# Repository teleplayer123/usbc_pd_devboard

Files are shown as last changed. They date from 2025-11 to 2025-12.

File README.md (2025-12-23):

### Description
A development board to experiment with USB-C PD via an STM32 and FUSB302. 

The [PD Logger](firmware/pd_logger) firmware logs USB C device attaches and dettaches as well
as the active CC pin. Connect to the board through UART and use a serial terminal to interact with 
the FUSB302 over I2C via the STM32F0. Logs will start showing once a PD capable device is detected.
A debug console menu can be accessed by pressing Enter in the terminal allowing direct writes and
reads to the FUSB302. Press "q" to exit the debug console and return to live logging.

### Dev Board
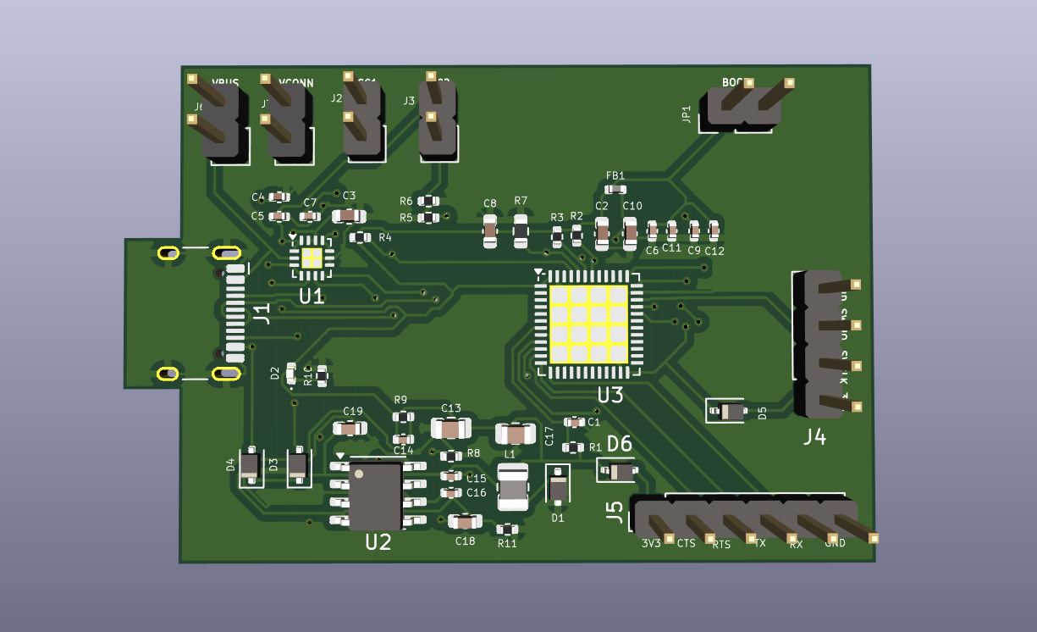
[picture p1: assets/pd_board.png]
DevBoardPreview


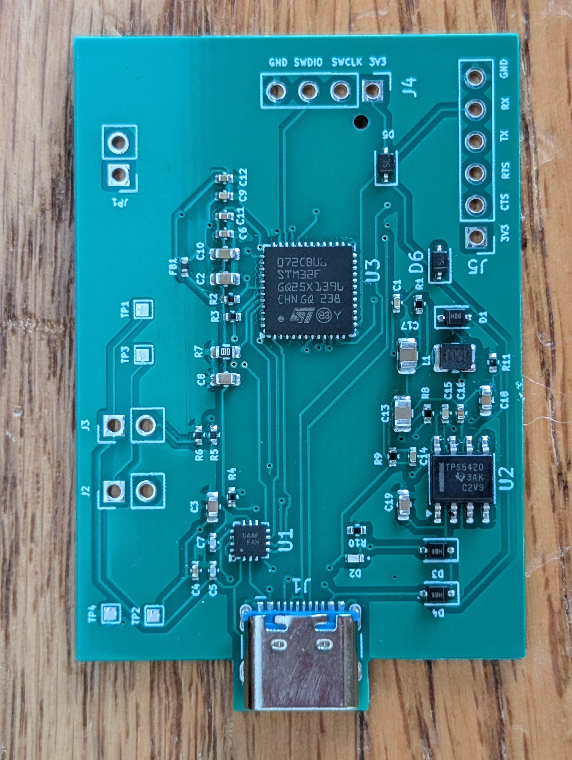
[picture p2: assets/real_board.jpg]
DevBoard


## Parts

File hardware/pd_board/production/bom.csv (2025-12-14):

Designator | Footprint | Quantity | Value | LCSC Part #
C1, C9 | 0402 | 2 | 10nF
C10 | 0603 | 1 | 1uF
C11, C12, C6 | 0402 | 3 | 100nF
C13, C17 | 0805 | 2 | 47uF
C14 | 0402 | 1 | 1800pF
C15 | 0402 | 1 | 0.01uF
C16 | 0402 | 1 | 150pF
C18 | 0603 | 1 | 0.1uF
C19, C2, C8 | 0603 | 3 | 4.7uF
C3 | 0603 | 1 | 10uF
C4 | 0402 | 1 | 0.1uF
C5, C7 | 0402 | 2 | 200pF
D1, D3, D4 | D_SOD-323F | 3 | BAT54J
D2 | 0402 | 1 | PWR_LED
D5, D6 | D_SOD-323 | 2 | 1N5819WS
FB1 | 0402 | 1 | 600R
J1 | USB_C_Receptacle_HCTL_HC-TYPE-C-16P-01A | 1 | USB_C_Receptacle_USB2.0_16P
J2 | PinHeader_1x01_P2.54mm_Vertical | 1 | CC1_TP
J3 | PinHeader_1x01_P2.54mm_Vertical | 1 | CC2_TP
J4 | PinHeader_1x04_P2.54mm_Vertical | 1 | Debug Port
J5 | PinHeader_1x06_P2.54mm_Vertical | 1 | UART_Port
J6 | PinHeader_1x02_P2.54mm_Vertical | 1 | VBUS_JP
J7 | PinHeader_1x02_P2.54mm_Vertical | 1 | VCONN_JP
J8 | PinHeader_1x02_P2.54mm_Vertical | 1 | VIN_ENA_JP
JP1 | PinHeader_1x02_P2.54mm_Vertical | 1 | Boot_Jumper
L1 | 1008 | 1 | 18uH
R1, R9 | 0402 | 2 | 10k
R10 | 0402 | 1 | 1k
R11 | 0402 | 1 | 5.9k
R2, R3, R4 | 0402 | 3 | 4.7k
R7 | 0603 | 1 | 100k
R8 | 0402 | 1 | 549R
U1 | WQFN-14-1EP_2.5x2.5mm_P0.5mm_EP1.45x1.45mm | 1 | FUSB302BMPX
U2 | SOIC-8_3.9x4.9mm_P1.27mm | 1 | TPS5420D
U3 | QFN-48-1EP_7x7mm_P0.5mm_EP5.6x5.6mm | 1 | STM32F072CBUx

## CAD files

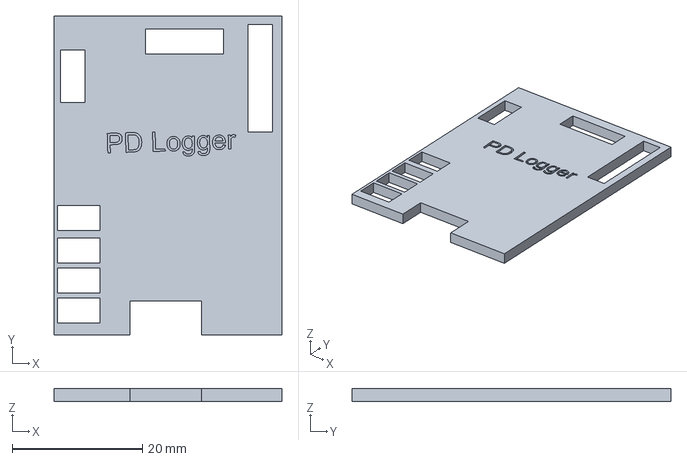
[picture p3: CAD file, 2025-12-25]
case/pd_board-Body001.3mf
35.0 x 49.0 x 2.00 mm

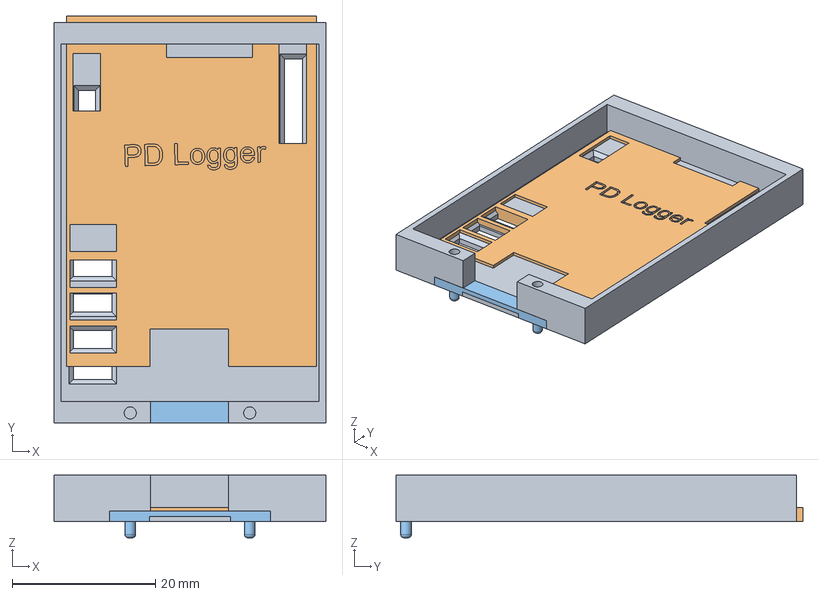
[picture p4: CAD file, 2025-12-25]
case/pd_board.FCStd
38.0 x 56.9 x 8.75 mm

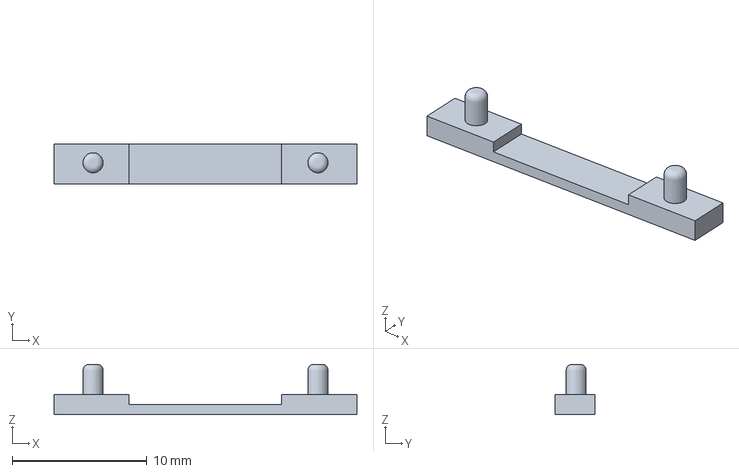
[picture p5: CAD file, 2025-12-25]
case/pd_board-Body002.3mf
22.5 x 3.00 x 3.75 mm

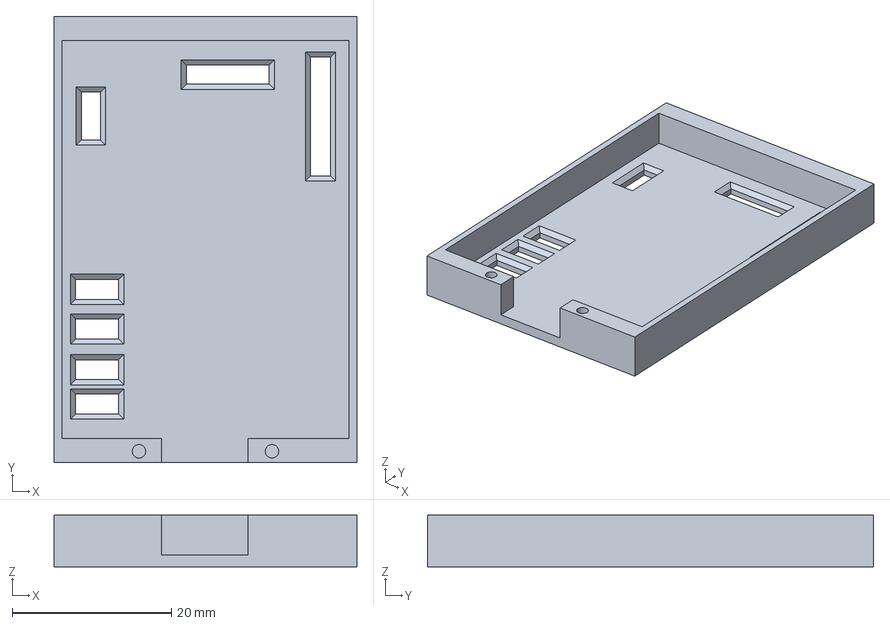
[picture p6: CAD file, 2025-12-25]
case/pd_board-Body.3mf
38.0 x 56.0 x 6.50 mm

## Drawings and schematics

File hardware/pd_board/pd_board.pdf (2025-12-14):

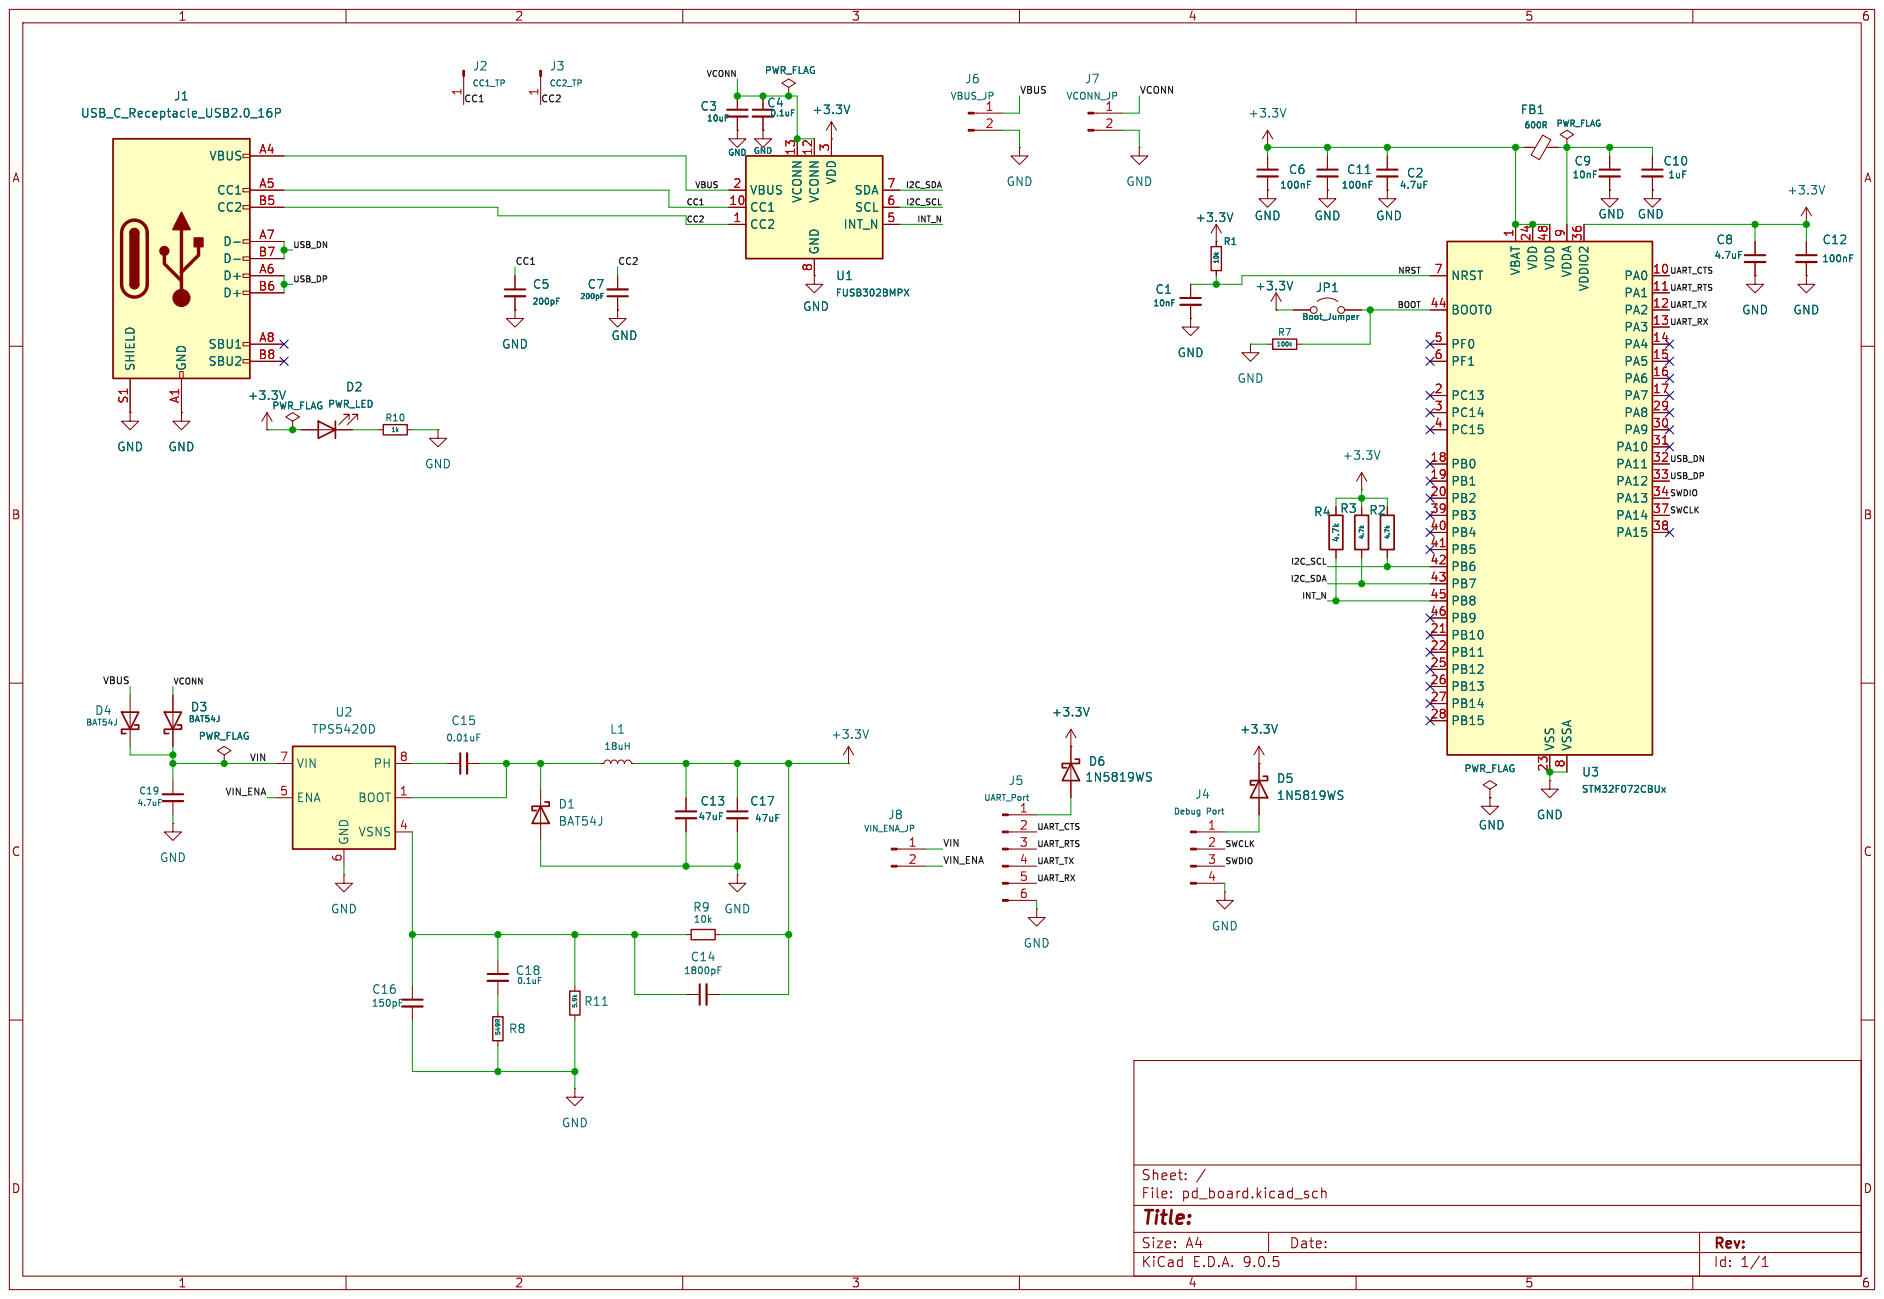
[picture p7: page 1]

1 VDD 24 VDD 48 VSS 23 VDDA

Id: 1/1 Title: File: pd_board.kicad_sch Sheet: /

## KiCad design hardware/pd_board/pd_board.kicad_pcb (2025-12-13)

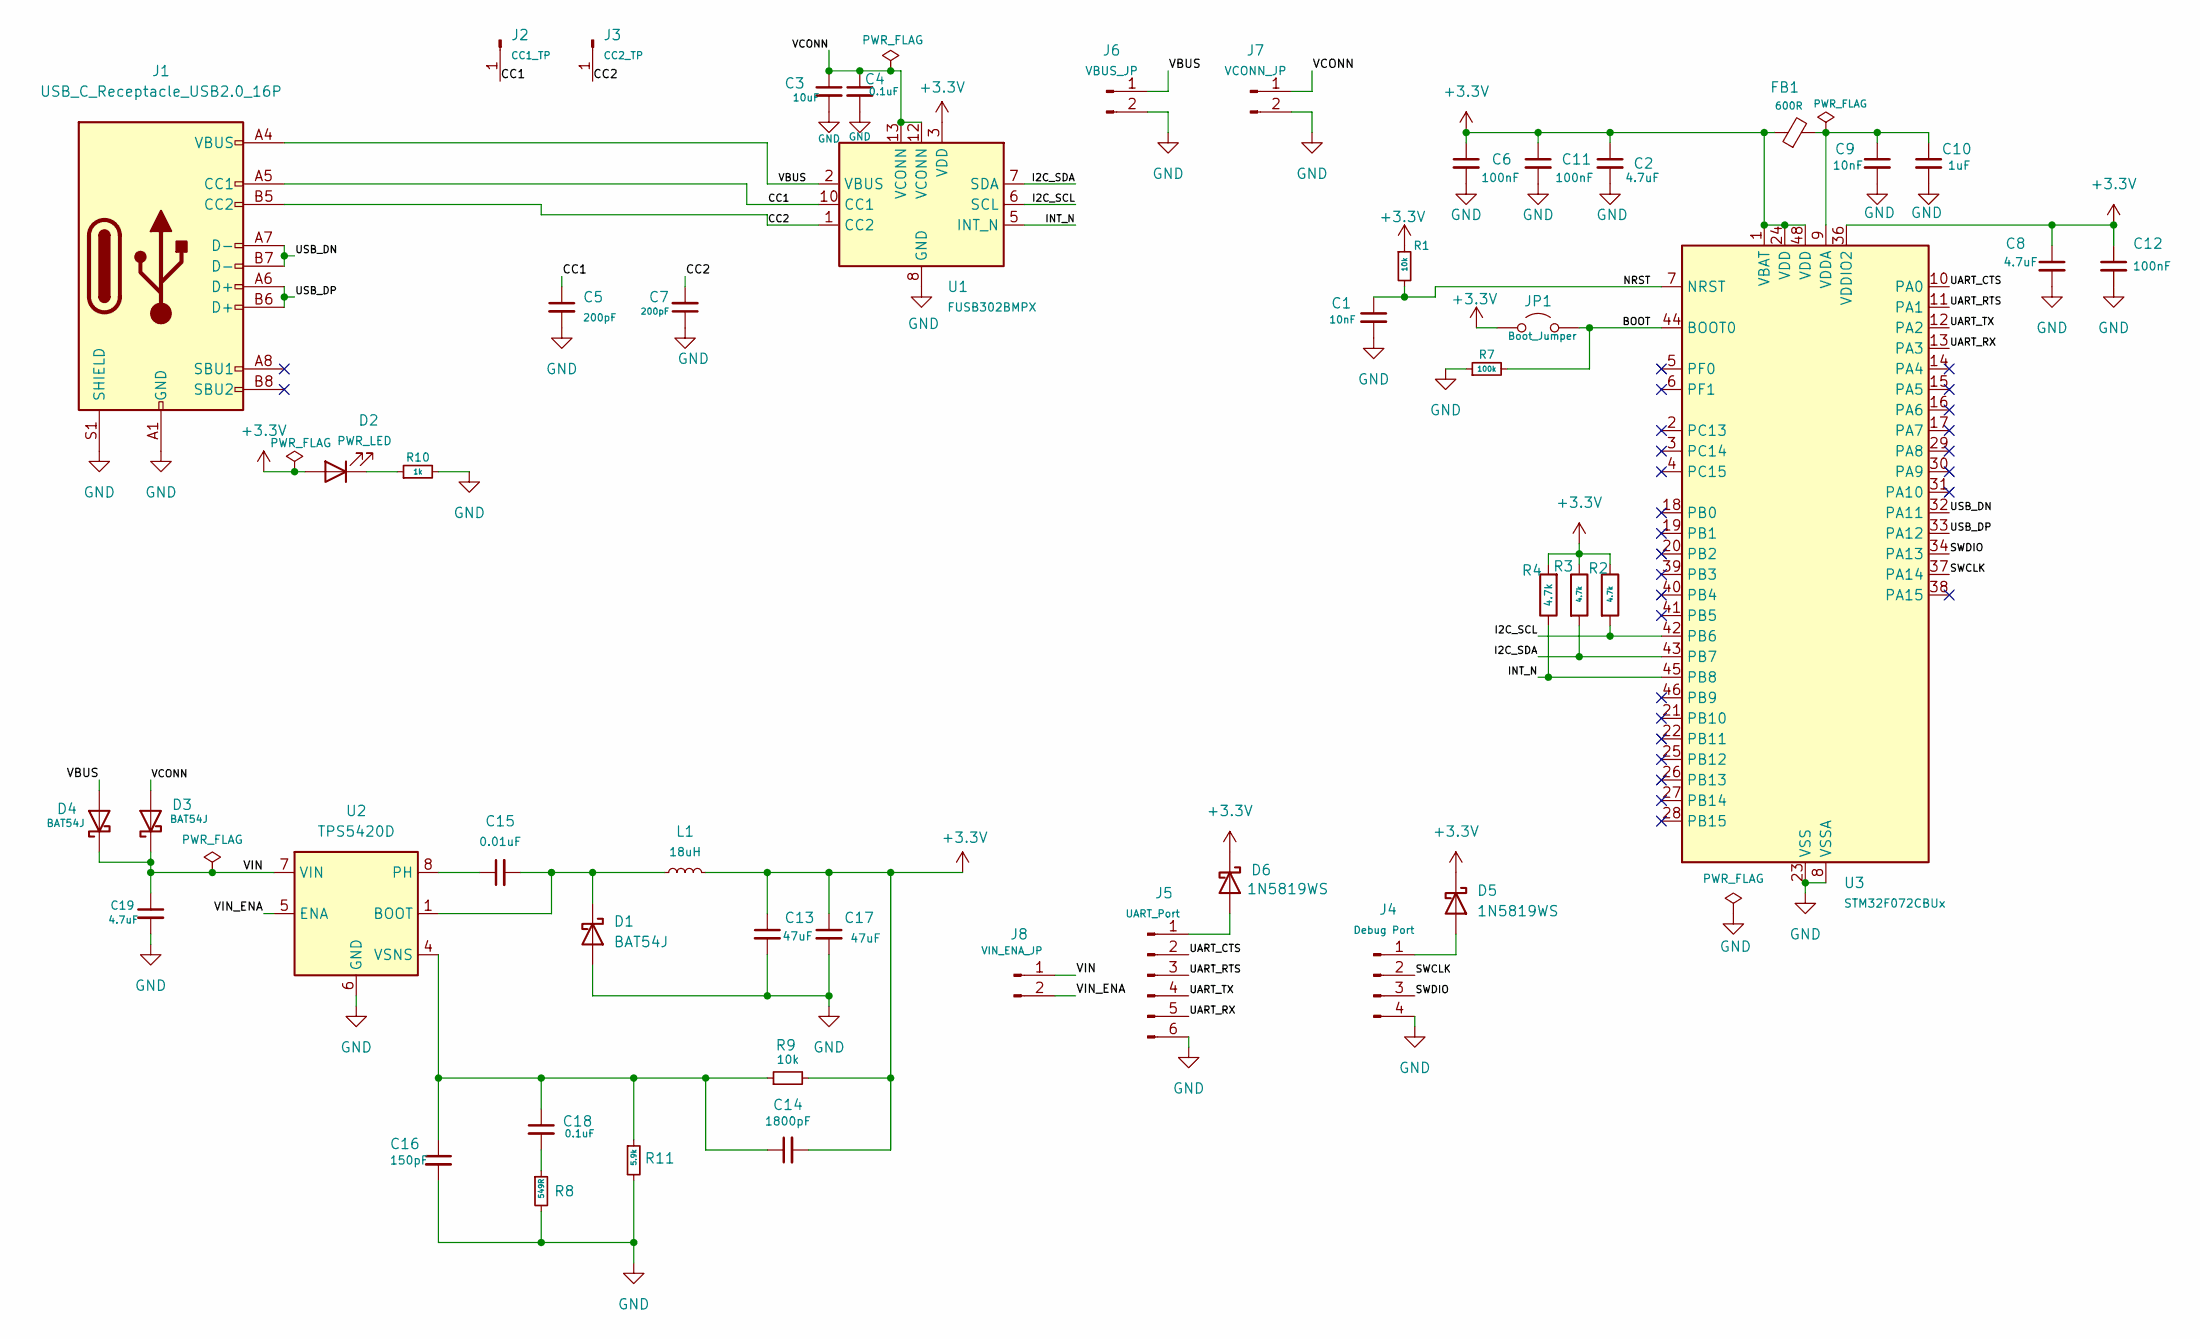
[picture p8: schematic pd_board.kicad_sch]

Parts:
C1, C9: 10nF; C_0402_1005Metric
C2, C8, C19: 4.7uF; C_0603_1608Metric
C3: 10uF; C_0603_1608Metric
C4: 0.1uF; C_0402_1005Metric
C5, C7: 200pF; C_0402_1005Metric
C6, C11, C12: 100nF; C_0402_1005Metric
C10: 1uF; C_0603_1608Metric
C13, C17: 47uF; C_0805_2012Metric
C14: 1800pF; C_0402_1005Metric
C15: 0.01uF; C_0402_1005Metric
C16: 150pF; C_0402_1005Metric
C18: 0.1uF; C_0603_1608Metric
D1, D3, D4: BAT54J; D_SOD-323F
D2: PWR_LED; LED_0402_1005Metric
D5, D6: 1N5819WS; D_SOD-323
FB1: 600R; L_0402_1005Metric
J1: USB_C_Receptacle_USB2.0_16P; USB_C_Receptacle_HCTL_HC-TYPE-C-16P-01A
J2: CC1_TP; PinHeader_1x01_P2.54mm_Vertical
J3: CC2_TP; PinHeader_1x01_P2.54mm_Vertical
J4: Debug Port; PinHeader_1x04_P2.54mm_Vertical
J5: UART_Port; PinHeader_1x06_P2.54mm_Vertical
J6: VBUS_JP; PinHeader_1x02_P2.54mm_Vertical
J7: VCONN_JP; PinHeader_1x02_P2.54mm_Vertical
J8: VIN_ENA_JP; PinHeader_1x02_P2.54mm_Vertical
JP1: Boot_Jumper; PinHeader_1x02_P2.54mm_Vertical
L1: 18uH; L_1008_2520Metric
R1, R9: 10k; R_0402_1005Metric
R2, R3, R4: 4.7k; R_0402_1005Metric
R7: 100k; R_0603_1608Metric
R8: 549R; R_0402_1005Metric
R10: 1k; R_0402_1005Metric
R11: 5.9k; R_0402_1005Metric
U1: FUSB302BMPX; WQFN-14-1EP_2.5x2.5mm_P0.5mm_EP1.45x1.45mm
U2: TPS5420D; SOIC-8_3.9x4.9mm_P1.27mm
U3: STM32F072CBUx; QFN-48-1EP_7x7mm_P0.5mm_EP5.6x5.6mm

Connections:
+3.3V: C2.1, C6.1, C8.1, C11.1, C12.1, C13.1, C14.2, C17.1, D2.2 (A), D5.1 (K), D6.1 (K), FB1.1, JP1.1 (A), L1.2, R1.1, R2.1, R3.1, R4.2, R9.2, U1.3 (VDD), U1.4 (VDD), U3.1 (VBAT), U3.24 (VDD), U3.36 (VDDIO2), U3.48 (VDD)
/BOOT: JP1.2 (B), R7.2, U3.44 (BOOT0)
/CC1: C5.1, J1.A5 (CC1), J2.1, U1.10 (CC1), U1.11 (CC1)
/CC2: C7.2, J1.B5 (CC2), J3.1, U1.1 (CC2), U1.14 (CC2)
/I2C_SCL: R2.2, U1.6 (SCL), U3.42 (PB6)
/I2C_SDA: R3.2, U1.7 (SDA), U3.43 (PB7)
/INT_N: R4.1, U1.5 (INT_N), U3.45 (PB8)
/NRST: C1.1, R1.2, U3.7 (NRST)
/SWCLK: J4.2, U3.37 (PA14)
/SWDIO: J4.3, U3.34 (PA13)
/UART_CTS: J5.2, U3.10 (PA0)
/UART_RTS: J5.3, U3.11 (PA1)
/UART_RX: J5.5, U3.13 (PA3)
/UART_TX: J5.4, U3.12 (PA2)
/USB_DN: J1.A7 (D-), J1.B7 (D-), U3.32 (PA11)
/USB_DP: J1.A6 (D+), J1.B6 (D+), U3.33 (PA12)
/VBUS: D4.2 (A), J1.A4 (VBUS), J1.A9 (VBUS), J1.B4 (VBUS), J1.B9 (VBUS), J6.1, U1.2 (VBUS)
/VCONN: C3.1, C4.1, D3.2 (A), J7.1, U1.12 (VCONN), U1.13 (VCONN)
/VIN: C19.1, D3.1 (K), D4.1 (K), J8.1, U2.7 (VIN)
/VIN_ENA: J8.2, U2.5 (ENA)
GND: C1.2, C2.2, C3.2, C4.2, C5.2, C6.2, C7.1, C8.2, C9.2, C10.2, C11.2, C12.2, C13.2, C16.2, C17.2, C19.2, D1.2 (A), J1.A1 (GND), J1.A12 (GND), J1.B1 (GND), J1.B12 (GND), J1.S1 (SHIELD), J4.4, J5.6, J6.2, J7.2, R7.1, R8.2, R10.2, R11.2, U1.8 (GND), U1.9 (GND), U1.15 (GND), U2.6 (GND), U3.8 (VSSA), U3.23 (VSS), U3.35 (VSS), U3.47 (VSS), U3.49 (VSS)
unnamed: C18.2, R8.1
unnamed: C15.2, D1.1 (K), L1.1, U2.1 (BOOT)
unnamed: D2.1 (K), R10.1
unnamed: D5.2 (A), J4.1
unnamed: D6.2 (A), J5.1
unnamed: C15.1, U2.8 (PH)
unnamed: C14.1, C16.1, C18.1, R9.1, R11.1, U2.4 (VSNS)
unnamed: C9.1, C10.1, FB1.2, U3.9 (VDDA)

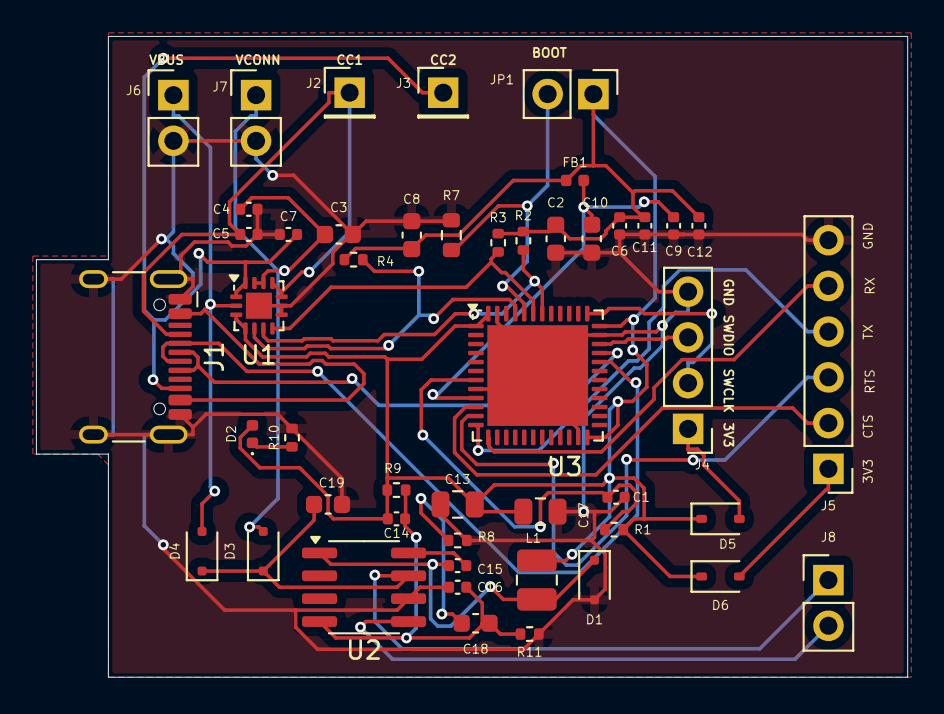
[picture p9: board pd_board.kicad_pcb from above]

Board: 2 copper layers, 48.4 x 35.6 mm, 48 parts (0 on the bottom side), 29 nets.

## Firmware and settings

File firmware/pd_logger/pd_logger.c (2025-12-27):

#include <libopencm3/stm32/rcc.h>
#include <libopencm3/stm32/gpio.h>
#include <libopencm3/stm32/usart.h>
#include <libopencm3/stm32/i2c.h>
#include <libopencm3/stm32/exti.h>
#include <libopencm3/cm3/nvic.h>
#include <libopencm3/cm3/cortex.h>
#include <libopencm3/cm3/systick.h>
#include <stdio.h>
#include <stdarg.h>
#include <string.h>
#include <stdlib.h>
#include <stdint.h>
#include <stdbool.h>
#include "fusb302.h"

/* ------------------------------------------------------------
 * Globals
 * ------------------------------------------------------------ */

volatile uint32_t system_millis;

static struct fusb302_chip_state {
    // CC1 = 0, CC2 = 1
	int cc_polarity;
	int vconn_enabled;
	// pulling up (DFP) = 1, pulling down (UFP) = 0
	int pulling_up;
	int rx_enable;
	uint8_t mdac_vnc;
	uint8_t mdac_rd;
    // device attached = 1, no device attached = 0
    int attached;
} state;

/* ------------------------------------------------------------
 * MCU Setup Functions
 * ------------------------------------------------------------ */

void sys_tick_handler(void)
{
    system_millis++;
}

static void clock_setup(void)
{
    rcc_clock_setup_in_hsi_out_48mhz();
    rcc_periph_clock_enable(RCC_GPIOA);
    rcc_periph_clock_enable(RCC_GPIOB);
    rcc_periph_clock_enable(RCC_USART2);
    rcc_periph_clock_enable(RCC_I2C1);
    // We need to enable the clock for SYSCFG to configure EXTI.
    rcc_periph_clock_enable(RCC_SYSCFG_COMP);
}

static void usart_setup(void)
{
    gpio_mode_setup(GPIOA, GPIO_MODE_AF, GPIO_PUPD_NONE, GPIO2 | GPIO3);
    gpio_set_af(GPIOA, GPIO_AF1, GPIO2 | GPIO3);
    // usart_disable(USART2);
    usart_set_baudrate(USART2, 115200);
    usart_set_databits(USART2, 8);
    usart_set_stopbits(USART2, USART_STOPBITS_1);
    usart_set_parity(USART2, USART_PARITY_NONE);
    usart_set_mode(USART2, USART_MODE_TX_RX);
    usart_set_flow_control(USART2, USART_FLOWCONTROL_NONE);
    usart_enable(USART2);
}

static void i2c_setup(void)
{
    gpio_mode_setup(GPIOB, GPIO_MODE_AF, GPIO_PUPD_NONE, GPIO6 | GPIO7);
    gpio_set_output_options(GPIOB, GPIO_OTYPE_OD, GPIO_OSPEED_25MHZ, GPIO6 | GPIO7);
    gpio_set_af(GPIOB, GPIO_AF1, GPIO6 | GPIO7);
    // gpio_mode_setup(GPIOB, GPIO_MODE_INPUT, GPIO_PUPD_NONE, GPIO8);
    gpio_mode_setup(GPIOB, GPIO_MODE_INPUT, GPIO_PUPD_PULLUP, GPIO8);

    // Hardware reset via RCC 
    rcc_peripheral_reset(&RCC_APB1RSTR, RCC_APB1RSTR_I2C1RST);
    rcc_peripheral_clear_reset(&RCC_APB1RSTR, RCC_APB1RSTR_I2C1RST);

    i2c_peripheral_disable(I2C1);
    i2c_set_speed(I2C1, i2c_speed_fm_400k, rcc_apb1_frequency / 1e6);
    i2c_peripheral_enable(I2C1);
}

static void systick_setup(void)
{
    systick_set_reload(rcc_ahb_frequency / 1000 - 1);
    systick_set_clocksource(STK_CSR_CLKSOURCE_AHB);
    systick_counter_enable();
    systick_interrupt_enable();
}

static void exti_setup(void)
{
    // Map PB8 to EXTI8
    exti_select_source(EXTI8, GPIOB);

    // Set EXTI8 to trigger on a falling edge (INT_N is active-low)
    exti_set_trigger(EXTI8, EXTI_TRIGGER_FALLING);

    // Enable EXTI8 interrupt line
    exti_enable_request(EXTI8);

    /* Source Identification: Inside the EXTI4_15_IRQHandler function, you will 
    need to check the specific pending register flag (PR register, bit 8) for EXTI 
    line 8 to determine if it was the source of the interrupt, as lines 4 through 15 
    all share this single handler */
    nvic_enable_irq(NVIC_EXTI4_15_IRQ); 
}

/* ------------------------------------------------------------
 * USART logging functions
 * ------------------------------------------------------------ */

/* simple blocking getchar/putchar */
int _write(int fd, char *ptr, int len)
{
    (void)fd;
    for (int i=0; i<len; i++) usart_send_blocking(USART2, ptr[i]);
    return len;
}

static void usart_send_char(char c)
{
    usart_send_blocking(USART2, c);
}

static char usart_getc(void)
{ 
    return usart_recv_blocking(USART2); 
}

static void usart_printf(const char *format, ...)
{
    char buf[2048];
    va_list args;
    va_start(args, format);
    vsnprintf(buf, sizeof(buf), format, args);
    va_end(args);

    for (const char *p = buf; *p; p++) {
        usart_send_char(*p);
        // Handle newline conversion for terminal compatibility
        if (*p == '\n') {
            usart_send_char('\r');
        }
    }
}

static void print_byte_as_bits(uint8_t byte, uint8_t reg)
{
    usart_printf("Reg %02X: ", reg);
    for (int i = 7; i >= 0; i--) { // Loop from most significant bit (7) to least significant (0)
        // Use a bitwise AND with a mask to check if the current bit is set
        // The mask is 1 shifted left by 'i' positions
        if ((byte >> i) & 1) { 
            usart_printf("1");
        } else {
            usart_printf("0");
        }
    }
    usart_printf("\r\n");
}

static void dump_bits(uint8_t reg, const struct bit_name *tbl)
{
    for (int i = 0; i <= 7; i++) {
        if (tbl[i].name == NULL)
            continue;  // skip unused bits             

        usart_printf("%s = %d\n", tbl[i].name, !!(reg & tbl[i].mask));
    }
}

static void hexdump(const uint8_t *data, size_t len)
{
    for (size_t i = 0; i < len; i += 16) {
        usart_printf("%04X: ", (unsigned int)i);
        
        // Print hex bytes
        for (size_t j = 0; j < 16 && i + j < len; j++) {
            usart_printf("%02X ", data[i + j]);
        }
        
        // Padding for alignment
        for (size_t j = len - i; j < 16; j++) {
            usart_printf("   ");
        }
        
        // Print ASCII representation
        usart_printf(" | ");
        for (size_t j = 0; j < 16 && i + j < len; j++) {
            uint8_t c = data[i + j];
            usart_printf("%c", (c >= 32 && c < 127) ? c : '.');
        }
        usart_printf("\r\n");
    }
}

static inline bool usart_rx_ready(void)
{
    return usart_get_flag(USART2, USART_FLAG_RXNE);
}

/* ------------------------------------------------------------
 * I2C read/write functions
 * ------------------------------------------------------------ */

static void fusb_write(uint8_t reg, uint8_t val)
{
    uint8_t tx_buf[2] = {reg, val};
    i2c_transfer7(I2C1, FUSB302_ADDR, tx_buf, 2, NULL, 0);
}

static inline uint8_t fusb_read(uint8_t reg)
{
    uint8_t v;
    i2c_transfer7(I2C1, FUSB302_ADDR, &reg, 1, &v, 1);
    return v;
}

static inline void fusb_read_fifo(uint8_t *buf, int len)
{
    uint8_t r = FUSB302_REG_FIFOS;
    i2c_transfer7(I2C1, FUSB302_ADDR, &r, 1, buf, len);
}

/* ------------------------------------------------------------
 * FUSB302 functions
 * ------------------------------------------------------------ */

static inline bool fusb_rx_empty(void) 
{
    return fusb_read(FUSB302_REG_STATUS1) & FUSB302_STATUS1_RX_EMPTY;
}

static void fusb_delay_ms(uint32_t ms)
{
    // This assumes SysTick is running at 1ms intervals.
    for (uint32_t i = 0; i < ms; i++) {
        // Wait for the SysTick flag to be set (1ms elapsed)
        while ((STK_CSR & STK_CSR_COUNTFLAG) == 0);
    }
}

static void fusb_delay_us(uint32_t us) {
    // At 48MHz, approximately 48 clock cycles per microsecond
    // Each NOP takes 1 cycle, loop overhead is minimal
    for (uint32_t i = 0; i < us * 6; i++) {
        __asm__("nop");
    }
}

static void fusb_reset(void)
{
    fusb_write(FUSB302_REG_RESET, FUSB302_RESET_SW);
    fusb_delay_ms(2);
}

static void fusb_pd_reset(void)
{
    fusb_write(FUSB302_REG_RESET, FUSB302_RESET_PD);
    fusb_delay_ms(2);
}

static void fusb_power_all(void)
{
    fusb_write(FUSB302_REG_POWER, FUSB302_POWER_ALL_ON);
    fusb_delay_ms(1);
}

// Print current state struct values for debugging
static void fusb_current_state(void)
{
    usart_printf("---- Current FUSB302 State ----\r\n");
    usart_printf("CC Polarity: %d\r\n", state.cc_polarity);
    usart_printf("VCONN Enabled: %d\r\n", state.vconn_enabled);
    if (state.pulling_up) {
        usart_printf("Pulling Up (DFP): %d\r\n", state.pulling_up);
    } else {
        usart_printf("Pulling Down (UFP): %d\r\n", state.pulling_up);
    }
    usart_printf("RX Enable: %d\r\n", state.rx_enable);
    usart_printf("MDAC VNC: 0x%02X\r\n", state.mdac_vnc);
    usart_printf("MDAC RD: 0x%02X\r\n", state.mdac_rd);
    if (state.attached) {
        usart_printf("Device Attached: True\r\n");
    } else {
        usart_printf("Device Attached: False\r\n");
    }
    usart_printf("---- End State ----\r\n");
}

/*
// unused functions being kept as reference for now...
static void fusb_setup_sniffer(void)
{    
    uint8_t reg;

    usart_printf("Initializing FUSB302 for PD Sniffing...\n");

    state.mdac_vnc = FUSB302_MEAS_MDAC_MV(PD_SRC_DEF_MV);
    state.mdac_rd = FUSB302_MEAS_MDAC_MV(PD_SRC_DEF_RD_MV);
    
    // Reset the FUSB302
    fusb_reset();

    // Power on
    fusb_power_all();

    // Configure Switches0: Enable measurement (passive detection) on CC1 and CC2
    reg = fusb_read(FUSB302_REG_SWITCHES0);
    reg |= (FUSB302_SW0_MEAS_CC1 | FUSB302_SW0_MEAS_CC2 | FUSB302_SW0_PDWN1 | FUSB302_SW0_PDWN2);
    fusb_write(FUSB302_REG_SWITCHES0, reg);

    // Configure Control1: Enable reception of all SOP packets
    fusb_write(FUSB302_REG_CONTROL1, FUSB302_CTL1_ENSOP1 | FUSB302_CTL1_ENSOP2 | FUSB302_CTL1_ENSOP1DB | FUSB302_CTL1_ENSOP2DB);

    // Enable Auto-CRC, Set sink role
    fusb_write(FUSB302_REG_SWITCHES1, FUSB302_SW1_AUTO_GCRC | FUSB302_SW1_SPECREV1 | FUSB302_SW1_SPECREV0);

    // Toggle to detect CC and establish UFP (Sink)
    fusb_write(FUSB302_REG_CONTROL2, FUSB302_CTL2_MODE_UFP | FUSB302_CTL2_WAKE_EN | FUSB302_CTL2_TOGGLE);

    // Unmask all interrupts
    fusb_write(FUSB302_REG_MASK, 0x00);
    fusb_write(FUSB302_REG_MASKA, 0x00);
    fusb_write(FUSB302_REG_MASKB, 0x00);

    // Reading interrupts clears them
    fusb_read(FUSB302_REG_INTERRUPT);
    fusb_read(FUSB302_REG_INTERRUPTA);
    fusb_read(FUSB302_REG_INTERRUPTB);
    fusb_delay_ms(2);

    // Set VCONN and polarity defaults
    state.vconn_enabled = 0;
    state.cc_polarity = 0;
    // Pull-down enabled
    state.pulling_up = 0;
    // RX enabled
    state.rx_enable = 1;

    usart_printf("FUSB302 configured for PD Sniffing.\n");
}

static void fusb_init_sink(void)
{
    // CONTROL1 Enable reception of all SOP packets
    fusb_write(FUSB302_REG_CONTROL1, FUSB302_CTL1_ENSOP1 | FUSB302_CTL1_ENSOP2 | FUSB302_CTL1_ENSOP1DB | FUSB302_CTL1_ENSOP2DB);

    // SWITCHES1 Enable Auto-CRC, Set sink role
    fusb_write(FUSB302_REG_SWITCHES1, FUSB302_SW1_AUTO_GCRC | FUSB302_SW1_SPECREV1 | FUSB302_SW1_SPECREV0);
    // CONTROL2 Toggle to detect CC and establish UFP (Sink)
    fusb_write(FUSB302_REG_CONTROL2, FUSB302_CTL2_MODE_UFP | FUSB302_CTL2_WAKE_EN | FUSB302_CTL2_TOGGLE);

    // SWITCHES0 Enable measurement (passive detection) on CC1 and CC2
    uint8_t reg = fusb_read(FUSB302_REG_SWITCHES0);
    reg |= (FUSB302_SW0_MEAS_CC1 | FUSB302_SW0_MEAS_CC2 | FUSB302_SW0_PDWN1 | FUSB302_SW0_PDWN2);
    fusb_write(FUSB302_REG_SWITCHES0, reg);

    usart_printf("FUSB302 initialized in Sink mode.\n");
}
*/

static void fusb_setup(void)
{
    uint8_t reg;

    state.mdac_vnc = FUSB302_MEAS_MDAC_MV(PD_SRC_DEF_MV);
    state.mdac_rd = FUSB302_MEAS_MDAC_MV(PD_SRC_DEF_RD_MV);

    // Reset FUSB302
    fusb_reset();

    // Power all
    fusb_power_all();

    // CONTROL3 Turn on retries and set number of retries
    reg = fusb_read(FUSB302_REG_CONTROL3);
    reg |= (FUSB302_CTL3_AUTO_RETRY | FUSB302_CTL3_NRETRIES_MASK);
    fusb_write(FUSB302_REG_CONTROL3, reg);

    // Create interrupt masks
    reg = 0xFF;
    // CC level changes
    reg &= ~FUSB302_MASK_BC_LVL;
    // Collisions
    reg &= ~FUSB302_MASK_COLLISION;
    // Alert
    reg &= ~FUSB302_MASK_ALERT;
    // Packet received with correct crc
    reg &= ~FUSB302_MASK_CRC_CHK;
    fusb_write(FUSB302_REG_MASK, reg);

    // MaskA reg masks
    reg = 0xFF;
    reg &= ~FUSB302_MASKA_RETRYFAIL;
    reg &= ~FUSB302_MASKA_HARDSENT;
    reg &= ~FUSB302_MASKA_TXSENT;
    reg &= ~FUSB302_MASKA_HARDRST;
    fusb_write(FUSB302_REG_MASKA, reg);
    
    // MaskB GoodCRC to ack pd message
    reg = 0xFF;
    reg &= ~FUSB302_MASKB_GCRCSENT;
    fusb_write(FUSB302_REG_MASKB, reg);

    // CONTROL0 Enable interrupt
    reg = fusb_read(FUSB302_REG_CONTROL0);
    reg &= ~FUSB302_CTL0_INT_MASK;
    fusb_write(FUSB302_REG_CONTROL0, reg);

    // Set state defaults
    state.vconn_enabled = 0;
    state.cc_polarity = 0;
    state.attached = 0;
}

static void fusb_check_status_regs(void)
{
    uint8_t reg;
    // Read and print status0 bits
    usart_printf("---- STATUS0 ----\r\n");
    reg = fusb_read(FUSB302_REG_STATUS0);
    dump_bits(reg, fusb302_status0_bits);
    usart_printf("\r\n");
    // Read and print status1 bits
    usart_printf("---- STATUS1 ----\r\n");
    reg = fusb_read(FUSB302_REG_STATUS1);
    dump_bits(reg, fusb302_status1_bits);
    usart_printf("\r\n");
    // Read and print status0a bits
    usart_printf("---- STATUS0A ----\r\n");
    reg = fusb_read(FUSB302_REG_STATUS0A);
    dump_bits(reg, fusb302_status0a_bits);
    usart_printf("\r\n");
    // Read and print status1a bits
    usart_printf("---- STATUS1A ----\r\n");
    reg = fusb_read(FUSB302_REG_STATUS1A);
    dump_bits(reg, fusb302_status1a_bits);
    usart_printf("\r\n");
}

static void check_rx_buffer(void)
{
    uint8_t rx_buffer[80];
    fusb_read_fifo(rx_buffer, 80);
    hexdump(rx_buffer, 80);
}

static int convert_bc_lvl(int bc_lvl)
{
    int tc_lvl = TYPEC_CC_VOLT_OPEN;
    if (state.pulling_up) {
        if (bc_lvl == 0x00) {
            tc_lvl = TYPEC_CC_VOLT_RA;
        } else if (bc_lvl < 0x03) {
            tc_lvl = TYPEC_CC_VOLT_RD;
        }
    } else {
        if (bc_lvl == 0x01) {
            tc_lvl = TYPEC_CC_VOLT_SNK_DEF;
        } else if (bc_lvl == 0x02) {
            tc_lvl = TYPEC_CC_VOLT_SNK_1_5;
        } else if (bc_lvl == 0x03) {
            tc_lvl = TYPEC_CC_VOLT_SNK_3_0;
        }
    }
    return tc_lvl;
}

static int fusb_measure_cc_pin_src(uint8_t cc_reg)
{
    // Read status from switches0 register
    uint8_t reg, sw0_orig, cc_lvl;
    reg = fusb_read(FUSB302_REG_SWITCHES0);
    sw0_orig = reg;
    // Clear measurement bits
    reg &= ~(FUSB302_SW0_MEAS_CC1 | FUSB302_SW0_MEAS_CC2);
    // Set measurement bit for desired CC pin
    if (cc_reg == FUSB302_SW0_MEAS_CC1) {
        reg |= FUSB302_SW0_PU_EN1;  // Measure CC1
    } else if (cc_reg == FUSB302_SW0_MEAS_CC2) {
        reg |= FUSB302_SW0_PU_EN2;  // Measure CC2
    }
    // Set CC measure bit
    reg |= cc_reg;
    // Set measurement switch
    fusb_write(FUSB302_REG_SWITCHES0, reg);
    // Set MDAC to default value
    uint8_t mdac = FUSB302_MEAS_MDAC_MV(PD_SRC_DEF_MV); // converts milivolts to MDAC code to write to MEASURE register
    fusb_write(FUSB302_REG_MEASURE, mdac);
    fusb_delay_us(250);
    // Read status register
    reg = fusb_read(FUSB302_REG_STATUS0);
    // Assume open
    cc_lvl = 0;
    // CC voltage below no connect threshold
    if ((reg & FUSB302_STATUS0_COMP) == 0) {
        fusb_write(FUSB302_REG_MEASURE, PD_SRC_DEF_RD_MV);
        fusb_delay_us(250);

        // Read status register
        reg = fusb_read(FUSB302_REG_STATUS0);

        cc_lvl = (reg & FUSB302_STATUS0_COMP) ? TYPEC_CC_VOLT_RD : TYPEC_CC_VOLT_RA;
    }
    // Restore original switches0 register
    fusb_write(FUSB302_REG_SWITCHES0, sw0_orig);
    return cc_lvl;
}

static void fusb_measure_cc_pin_snk(uint8_t *cc1, uint8_t *cc2)
{
    uint8_t reg, orig_cc1, orig_cc2, bc_lvl_cc1, bc_lvl_cc2;

    // Measure cc1
    reg = fusb_read(FUSB302_REG_SWITCHES0);
    if (reg & FUSB302_SW0_MEAS_CC1) {
        orig_cc1 = 1;
    } else {
        orig_cc1 = 0;
    }
    if (reg & FUSB302_SW0_MEAS_CC2) {
        orig_cc2 = 1;
    } else {
        orig_cc2 = 0;
    }

    // Disable cc2 measurement switch, enable cc1 measurement switch
    reg &= ~FUSB302_SW0_MEAS_CC2;
    reg |= FUSB302_SW0_MEAS_CC1;
    fusb_write(FUSB302_REG_SWITCHES0, reg);
    // Wait for measurement
    fusb_delay_us(250);
    // Read cc1 measurement
    bc_lvl_cc1 = fusb_read(FUSB302_REG_STATUS0);
    // Read bc_lvl 
    bc_lvl_cc1 &= (FUSB302_STATUS0_BC_LVL0 | FUSB302_STATUS0_BC_LVL1);
    usart_printf("CC1 Sink BC_LVL: %02X\r\n", bc_lvl_cc1);

    // Measure cc2
    reg = fusb_read(FUSB302_REG_SWITCHES0);
    // Disable cc1 measurement switch and enable cc2 measurement switch
    reg &= ~FUSB302_SW0_MEAS_CC1;
    reg |= FUSB302_SW0_MEAS_CC2;
    fusb_write(FUSB302_REG_SWITCHES0, reg);
    // Wait on measurement
    fusb_delay_us(250);
    // Read cc2 measurement
    bc_lvl_cc2 = fusb_read(FUSB302_REG_STATUS0);
    // Read bc_lvl
    bc_lvl_cc2 &= (FUSB302_STATUS0_BC_LVL0 | FUSB302_STATUS0_BC_LVL1);
    usart_printf("CC2 Sink BC_LVL: %02X\r\n", bc_lvl_cc2);

    *cc1 = convert_bc_lvl(bc_lvl_cc1);
    *cc2 = convert_bc_lvl(bc_lvl_cc2);

    // Restore switches0 to orignal state
    reg = fusb_read(FUSB302_REG_SWITCHES0);
    if (orig_cc1) {
        reg |= FUSB302_SW0_MEAS_CC1;
    } else {
        reg &= ~FUSB302_SW0_MEAS_CC1;
    }
    if (orig_cc2) {
        reg |= FUSB302_SW0_MEAS_CC2;
    } else {
        reg &= ~FUSB302_SW0_MEAS_CC2;
    }
    fusb_write(FUSB302_REG_SWITCHES0, reg);
}

static void fusb_enable_gcrc(bool enable)
{
    // AUTO_GCRC is in SWITCHES1 register
    uint8_t reg = fusb_read(FUSB302_REG_SWITCHES1);
    if (enable) {
        reg |= FUSB302_SW1_AUTO_GCRC;
    } else {
        reg &= ~FUSB302_SW1_AUTO_GCRC;
    }
}

static int fusb_check_cc_pin_snk(void)
{
    // return 0 for cc1, 1 for cc2
    int ret = 0; // default cc1
    uint8_t cc1, cc2;
    fusb_measure_cc_pin_snk(&cc1, &cc2);
    if (cc1 > cc2) {
        ret = 0;
        state.cc_polarity = 0;
    } else {
        ret = 1;
        state.cc_polarity = 1;
    }
    return ret;
}

static int fusb_check_cc_pin(void)
{
    // return 0 for cc1, 1 for cc2
    int ret = 0; // default cc1
    if (state.pulling_up) {
        // measure cc line for source
        int cc1_lvl = fusb_measure_cc_pin_src(FUSB302_SW0_MEAS_CC1);
        int cc2_lvl = fusb_measure_cc_pin_src(FUSB302_SW0_MEAS_CC2);
        if (cc1_lvl != TYPEC_CC_VOLT_OPEN && cc2_lvl == TYPEC_CC_VOLT_OPEN) {
            ret = 0; // Device detected on CC1
            state.cc_polarity = 0;
        } else if (cc2_lvl != TYPEC_CC_VOLT_OPEN && cc1_lvl == TYPEC_CC_VOLT_OPEN) {
            ret = 1; // Device detected on CC2
            state.cc_polarity = 1;
        }
    } else {
        ret = fusb_check_cc_pin_snk();
    }
    return ret;
}

static int fusb_mdac_comp(int mdac)
{
    int orig_reg, reg;
    // save original REG_MEASURE register
    orig_reg = fusb_read(FUSB302_REG_MEASURE);
    // set mdac to reg_measure bits 0-5 and set bit 6 to measure vbus
    fusb_write(FUSB302_REG_MEASURE, (mdac & FUSB302_MEAS_MDAC_MASK) | FUSB302_MEAS_VBUS);
    fusb_delay_us(350);
    // Read status0 register, if STATUS0_COMP=1 then vbus is higher than (mdac + 1) * 0.42V
    reg = fusb_read(FUSB302_REG_STATUS0);
    // restore original value
    fusb_write(FUSB302_REG_MEASURE, orig_reg);
    return reg & FUSB302_STATUS0_COMP;
}

// Returns voltage on VBUS in mV
static int fusb_measure_vbus_voltage(void)
{
    int vbus; 
    int mdac = 0;
    // compare vbus with mdac voltage
    // check each bit of reg_measure [5:0]
    for (int i = 5; i >= 0; i--) {
        if (fusb_mdac_comp(mdac | (1 << i))) {
            mdac |= (1 << i);
        }
    }
    vbus = (mdac + 1) * 420;
    return vbus;
}

static int fusb_measure_cc_voltage(bool cc1)
{
    uint8_t sw0 = fusb_read(FUSB302_REG_SWITCHES0);
    uint8_t meas = fusb_read(FUSB302_REG_MEASURE);

    // Disable Rd and select CC pin
    uint8_t new_sw0 = sw0 & ~(FUSB302_SW0_PDWN1 | FUSB302_SW0_PDWN2);
    new_sw0 &= ~(FUSB302_SW0_MEAS_CC1 | FUSB302_SW0_MEAS_CC2);
    new_sw0 |= cc1 ? FUSB302_SW0_MEAS_CC1 : FUSB302_SW0_MEAS_CC2;

    fusb_write(FUSB302_REG_SWITCHES0, new_sw0);

    uint8_t dac;
    for (dac = 0; dac < 64; dac++) {
        fusb_write(FUSB302_REG_MEASURE, (meas & ~FUSB302_MEAS_MDAC_MASK) | dac);

        // comparator settle
        fusb_delay_us(350);

        uint8_t st = fusb_read(FUSB302_REG_STATUS0);

        // COMP = 1 → CC > DAC 
        if (!(st & FUSB302_STATUS0_COMP))
            break;
    }

    // Restore registers
    fusb_write(FUSB302_REG_MEASURE, meas);
    fusb_write(FUSB302_REG_SWITCHES0, sw0);

    // Approximate conversion to mV
    return dac * 42;
}

static int fusb_int_vbusok(void)
{
    // Note: interrupt is cleared when read
    // return 1 for vbusok else 0
    uint8_t reg = fusb_read(FUSB302_REG_INTERRUPT);
    if (reg & FUSB302_INT_VBUSOK) {
        return 1;
    } else {
        return 0;
    }
}

static int fusb_check_cc_voltage(void)
{
    bool cc1;
    if (state.cc_polarity)
        cc1 = false;
    else
        cc1 = true;
    int cc_mvolt = fusb_measure_cc_voltage(cc1);
    return cc_mvolt;
}

// function to print status info for debugging
static void fusb_get_status(void)
{
    fusb_check_status_regs();
    usart_printf("INT pin=%02X\r\n", gpio_get(GPIOB, GPIO8) ? 1 : 0);
    fusb_current_state();
    if (!fusb_rx_empty()) {
        check_rx_buffer();
    }
    int vbus_voltage = fusb_measure_vbus_voltage();
    usart_printf("VBUS Voltage: %d mV\r\n", vbus_voltage);
    int cc_volt = fusb_check_cc_voltage();
    usart_printf("CC voltage: %d mV\r\n", cc_volt);
}
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
int main(void)
{
    clock_setup();
    systick_setup();
    usart_setup();
    i2c_setup();
    exti_setup(); 

    fusb_setup();

    while (1) {
        if (usart_rx_ready()) {
            char c = usart_recv(USART2);
            if (c=='\r' || c=='\n') {
                usart_printf("Logging paused. Entering debug menu...\r\n");
                debug_cli();
            } 
        }
        poll();
        fusb_delay_ms(1000);
    }
}
